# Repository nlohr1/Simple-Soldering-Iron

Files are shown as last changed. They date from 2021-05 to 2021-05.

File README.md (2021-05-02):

# Simple-Soldering-Iron
Simple Soldering-Iron - reverse-engeneered and modified to a half-phase-"dimmer", adding a diode for 230VAC.

Many Cheap Soldering-Irons came with simple Phase control steering, similar to dimmer-controls for lamps.  
Originally dimensioned for 115VAC, they are overheating at 230VAC, burning through in short time, because  
the Wattage becomes four times greater as intended.  
If you purchased one of these, its no need to give up - simply convert the circuit from full phase-control  
to a half phase-control, insering a small generic Diode between the RC-link and the Diac, so this Diode  
lets pass only one phase of the main-voltage. Therefore the generated power results normal (about 60W) and  
temperatures of the iron don't run-away.

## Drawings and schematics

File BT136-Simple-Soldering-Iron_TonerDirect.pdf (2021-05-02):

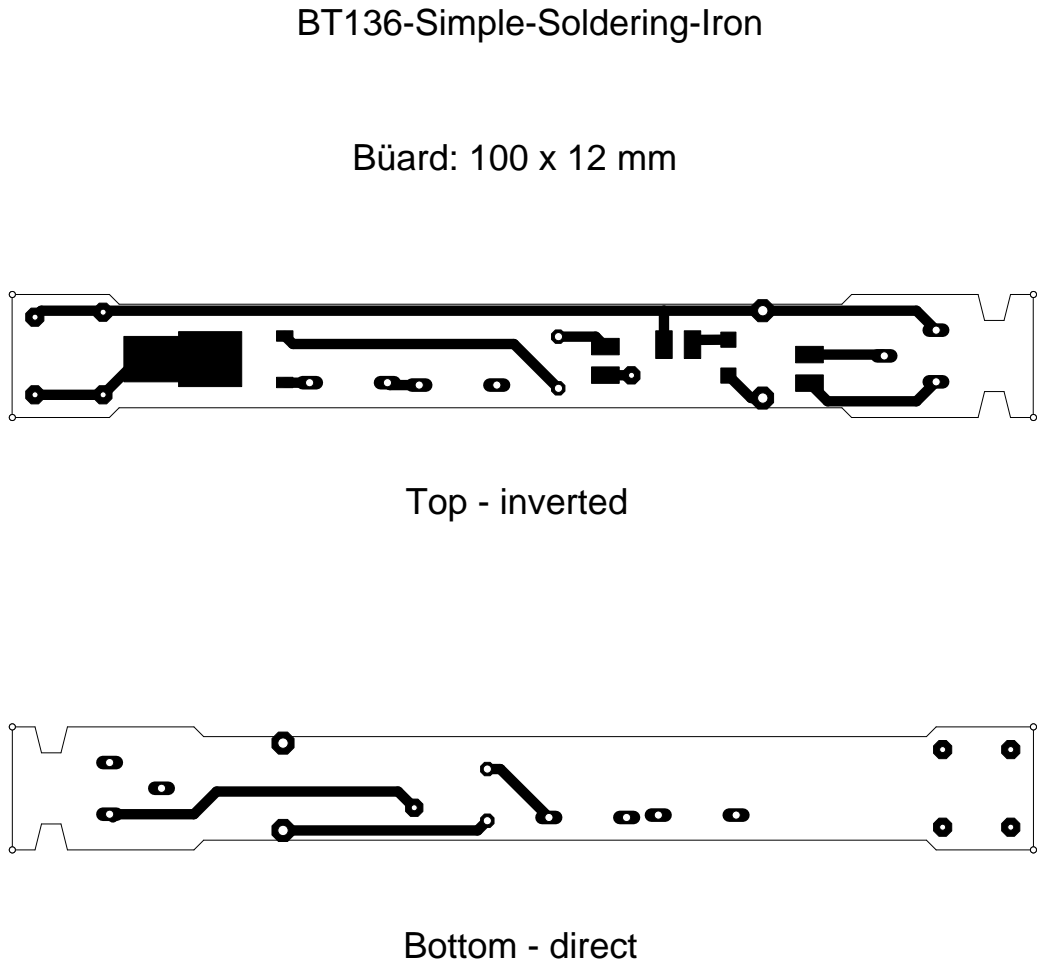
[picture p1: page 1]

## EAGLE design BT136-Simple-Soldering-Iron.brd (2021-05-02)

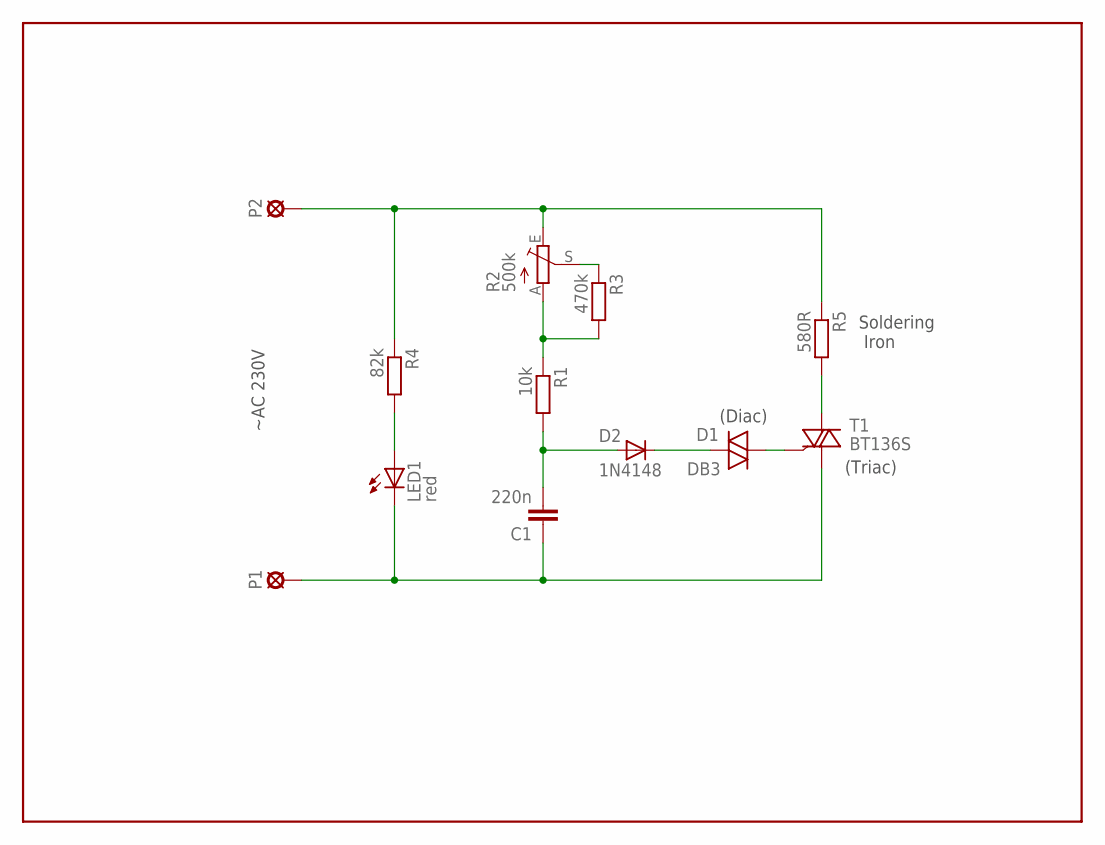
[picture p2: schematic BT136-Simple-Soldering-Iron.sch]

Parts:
C1: 220n; C050-025X075
D1: DB3; ER900
D2: 1N4148; DO35-7
LED1: red; SML1206
P1, P2: LSP10
R1: 10k; R1210
R2: 500k; RS3
R3: 470k; R1210
R4: 82k; R1210
R5: 580R; 0207/7
T1: BT136S; DPAK

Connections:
unnamed: D1.1, T1.3 (G)
unnamed: C1.2, D2.A, R1.2
unnamed: C1.1, LED1.C, P1.MP, T1.1 (A1)
unnamed: R1.1, R2.A, R3.2
unnamed: R2.S, R3.1
unnamed: R5.2, T1.4 (A2)
unnamed: P2.MP, R2.E, R4.1, R5.1
unnamed: D1.2, D2.C
unnamed: LED1.A, R4.2

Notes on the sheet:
Soldering Iron
~AC 230V
(Diac)
(Triac)

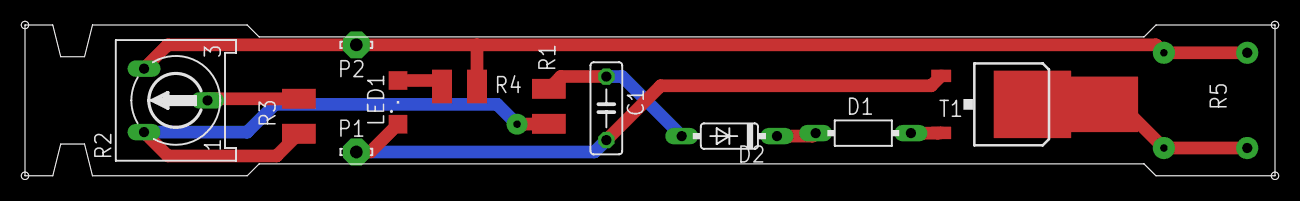
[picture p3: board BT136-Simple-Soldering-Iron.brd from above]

Board: 2 copper layers, 100.0 x 12.1 mm, 12 parts (1 on the bottom side), 9 nets.

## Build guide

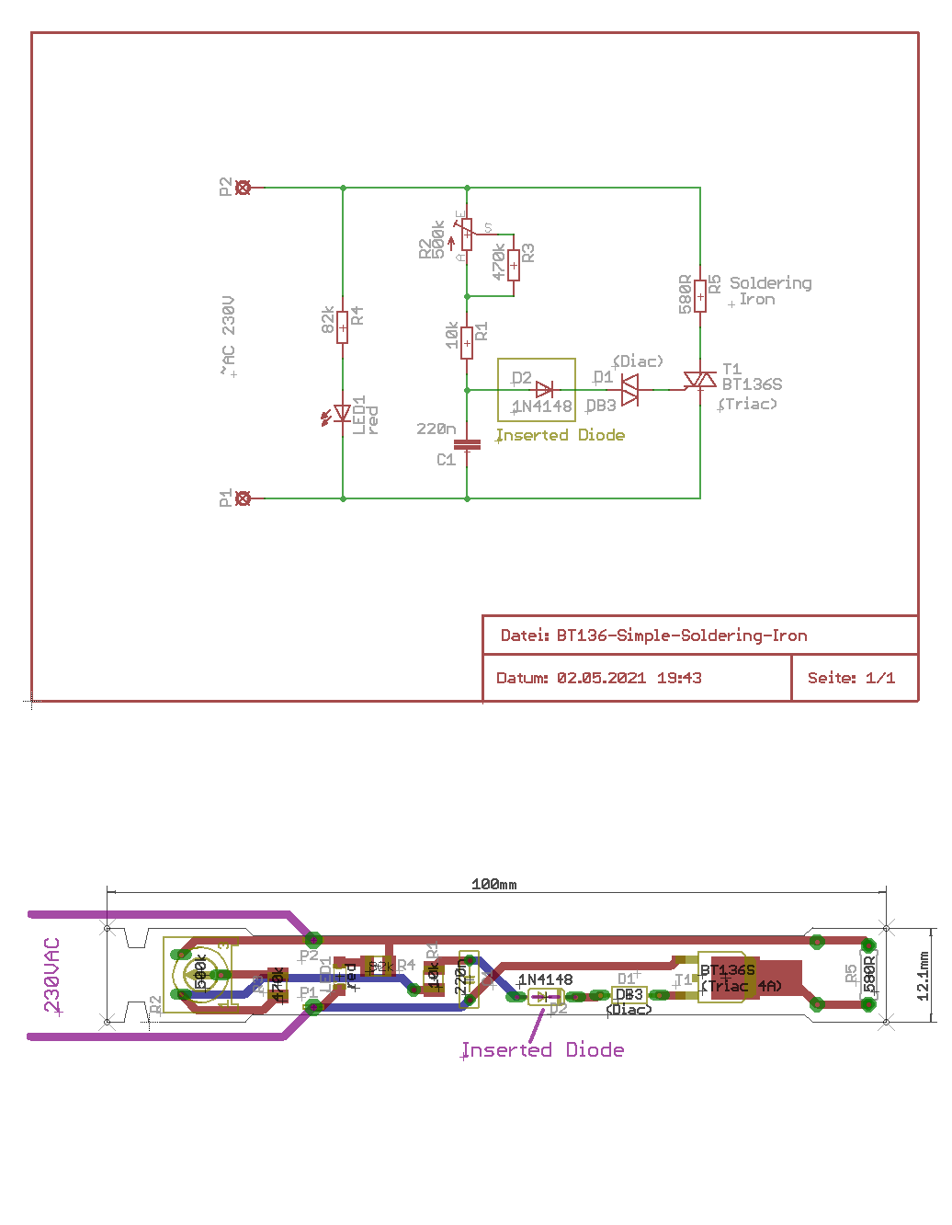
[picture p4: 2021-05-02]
BT136-Simple-Soldering-Iron.png
